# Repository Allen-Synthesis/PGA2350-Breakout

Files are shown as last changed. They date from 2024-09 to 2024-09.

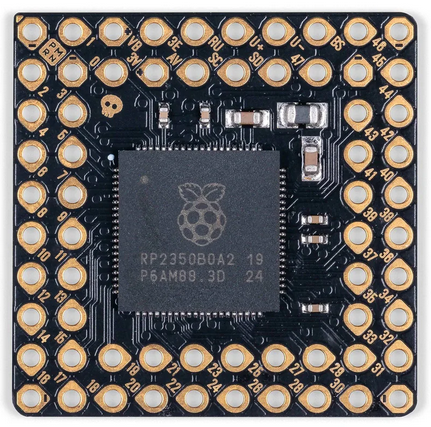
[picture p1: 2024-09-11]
images/PGA2350.png

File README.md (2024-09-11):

# PGA2350-breakout
### Pimoroni PGA2350 Breakout board for breadboard development of Eurorack modules



At the time I'm writing this, the only development board I can find for sale which utilises the B variant of the RP2350 *and* breaks out all of the extra ADCs it offers, is the [Pimoroni PGA2350](https://shop.pimoroni.com/products/pga2350?variant=42092629229651), however it is not a breadboard compatible.  
This board adapts the PGA2350 to allow it to be used for Eurorack development with a breadboard, breaking out all required connections including routing Eurorack power from a standard header to pin headers which can be connected to a breadboard's rails using jumper wire.  
The USB connections are arranged so that an [Adafruit USB Micro-B Breakout Board](https://www.adafruit.com/product/1833) (also sold by [Pimoroni](https://shop.pimoroni.com/products/adafruit-usb-micro-b-breakout-board?variant=821196557)) can be soldered directly to the board.

*NOTE: The first PCB order for these boards was tested on 10/09/2024 and appears to all work as expected. Not every GPIO has been tested, however the design is likely functional. Aesthetic improvements for version 1.1 (outlined below) have now been applied but no new boards have yet been ordered for testing. Order using the files in this repository with my blessing but at your own risk*

Pending changes based on version 1.0:
1. ~~Increment version to 1.1~~
1. ~~Alter pin header footprints to remove square pad for 1x2, 1x5, and 2x5~~
1. ~~Add JLC PCB order number text to the back~~
1. ~~Use consistent . or / in version date~~
1. ~~Remove J12 reference text~~
1. ~~Add ground stitching vias~~
1. ~~Use arrow to label PGA2350 and then use internal space to show orientation~~
1. Measure the USB breakout board and adjust position so that the edge is flush (USB already flush enough)
1. ~~Add lines between the labels and pins for rest of the headers as has been done for the GPIO headers~~
1. Add artwork to the back (and front?) to make use of the space (Text rearranged and logos swapped to copper layer, no more art added)

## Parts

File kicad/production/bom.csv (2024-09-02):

Designator | Footprint | Quantity | Value | LCSC Part #
J1, J11, J3, J9 | pin-socket-2.54mm-01x02 | 4 | Conn_01x02_Pin
J10, J5, J6, J7, J8 | pin-socket-2.54mm-02x05 | 5 | Conn_02x05_Counter_Clockwise
J12 | pin-header-2.54mm-01x03 | 1 | Conn_01x03_Pin
J2 | power-header-10-pin | 1 | Conn_02x05_Odd_Even
J4 | pin-header-2.54mm-01x05 | 1 | Conn_01x05_Pin
U1 | PGA2350 | 1 | ~

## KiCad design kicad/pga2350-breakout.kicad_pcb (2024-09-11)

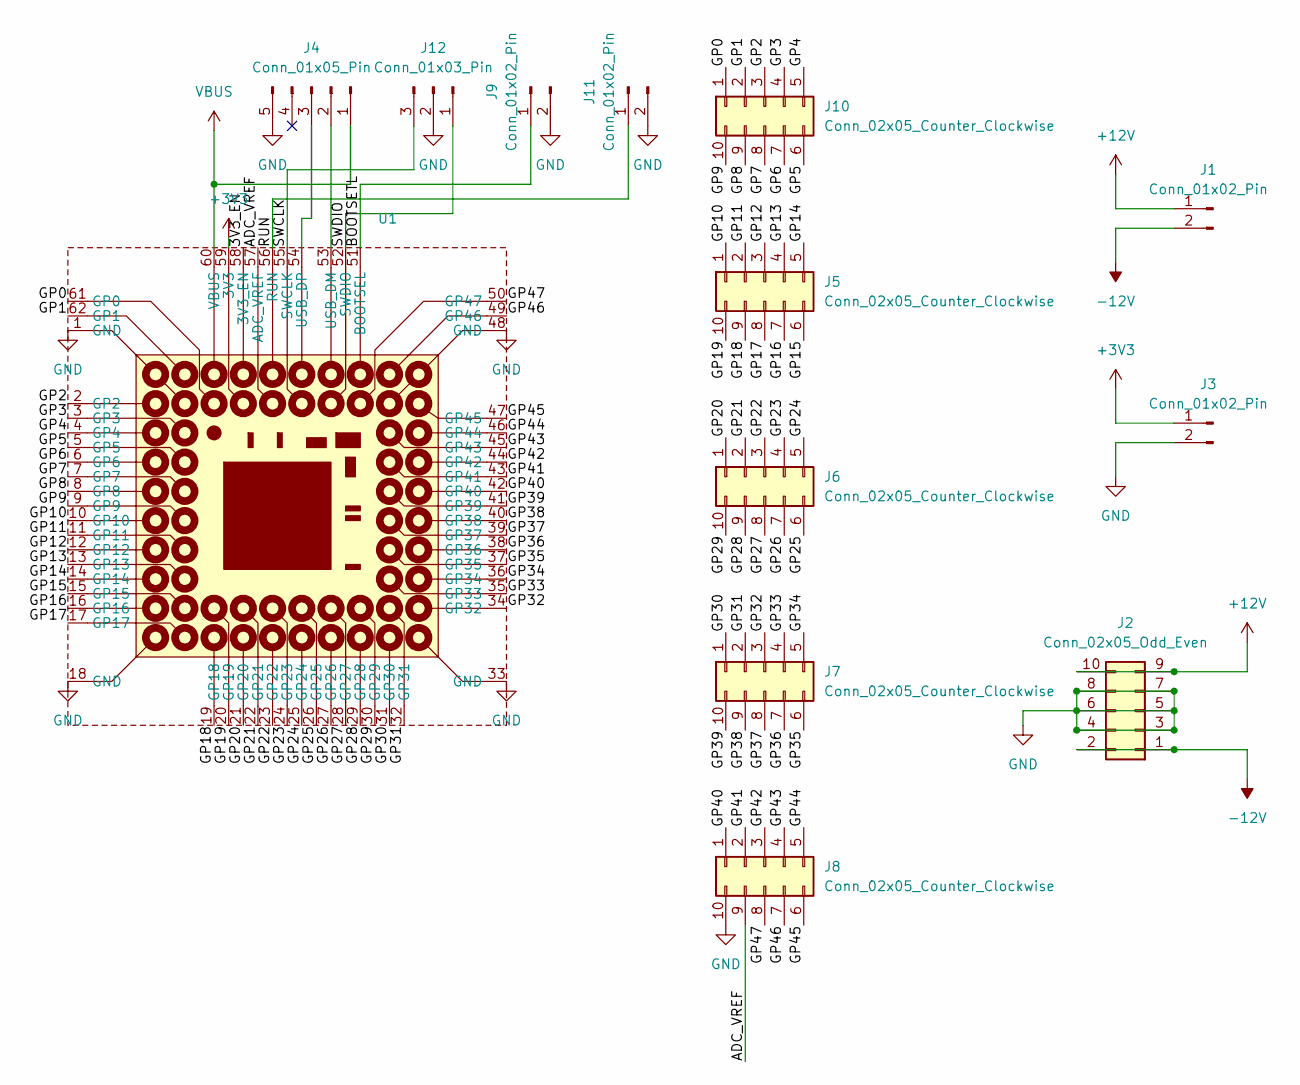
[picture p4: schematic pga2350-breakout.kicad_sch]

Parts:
J1, J3, J9, J11: Conn_01x02_Pin; pin-socket-2.54mm-01x02
J2: Conn_02x05_Odd_Even; power-header-10-pin
J4: Conn_01x05_Pin; pin-header-2.54mm-01x05
J5, J6, J7, J8, J10: Conn_02x05_Counter_Clockwise; pin-socket-2.54mm-02x05
J12: Conn_01x03_Pin; pin-header-2.54mm-01x03
U1: PGA2350

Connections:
+3V3: J3.1, U1.59 (3V3)
+12V: J1.1, J2.9, J2.10
-12V: J1.2, J2.1, J2.2
/3V3_EN: U1.58 (3V3_EN)
/ADC_VREF: J8.9, U1.57 (ADC_VREF)
/BOOTSETL: J9.1, U1.51 (BOOTSEL)
/GP0: J10.1, U1.61 (GP0)
/GP1: J10.2, U1.62 (GP1)
/GP2: J10.3, U1.2 (GP2)
/GP3: J10.4, U1.3 (GP3)
/GP4: J10.5, U1.4 (GP4)
/GP5: J10.6, U1.5 (GP5)
/GP6: J10.7, U1.6 (GP6)
/GP7: J10.8, U1.7 (GP7)
/GP8: J10.9, U1.8 (GP8)
/GP9: J10.10, U1.9 (GP9)
/GP10: J5.1, U1.10 (GP10)
/GP11: J5.2, U1.11 (GP11)
/GP12: J5.3, U1.12 (GP12)
/GP13: J5.4, U1.13 (GP13)
/GP14: J5.5, U1.14 (GP14)
/GP15: J5.6, U1.15 (GP15)
/GP16: J5.7, U1.16 (GP16)
/GP17: J5.8, U1.17 (GP17)
/GP18: J5.9, U1.19 (GP18)
/GP19: J5.10, U1.20 (GP19)
/GP20: J6.1, U1.21 (GP20)
/GP21: J6.2, U1.22 (GP21)
/GP22: J6.3, U1.23 (GP22)
/GP23: J6.4, U1.24 (GP23)
/GP24: J6.5, U1.25 (GP24)
/GP25: J6.6, U1.26 (GP25)
/GP26: J6.7, U1.27 (GP26)
/GP27: J6.8, U1.28 (GP27)
/GP28: J6.9, U1.29 (GP28)
/GP29: J6.10, U1.30 (GP29)
/GP30: J7.1, U1.31 (GP30)
/GP31: J7.2, U1.32 (GP31)
/GP32: J7.3, U1.34 (GP32)
/GP33: J7.4, U1.35 (GP33)
/GP34: J7.5, U1.36 (GP34)
/GP35: J7.6, U1.37 (GP35)
/GP36: J7.7, U1.38 (GP36)
/GP37: J7.8, U1.39 (GP37)
/GP38: J7.9, U1.40 (GP38)
/GP39: J7.10, U1.41 (GP39)
/GP40: J8.1, U1.42 (GP40)
/GP41: J8.2, U1.43 (GP41)
/GP42: J8.3, U1.44 (GP42)
/GP43: J8.4, U1.45 (GP43)
/GP44: J8.5, U1.46 (GP44)
/GP45: J8.6, U1.47 (GP45)
/GP46: J8.7, U1.49 (GP46)
/GP47: J8.8, U1.50 (GP47)
/RUN: J11.1, U1.56 (RUN)
/SWCLK: J12.3, U1.55 (SWCLK)
/SWDIO: J12.1, U1.52 (SWDIO)
GND: J2.3, J2.4, J2.5, J2.6, J2.7, J2.8, J3.2, J4.5, J8.10, J9.2, J11.2, J12.2, U1.1 (GND), U1.18 (GND), U1.33 (GND), U1.48 (GND)
unnamed: J4.2, U1.53 (USB_DM)
unnamed: J4.3, U1.54 (USB_DP)
VBUS: J4.1, U1.60 (VBUS)

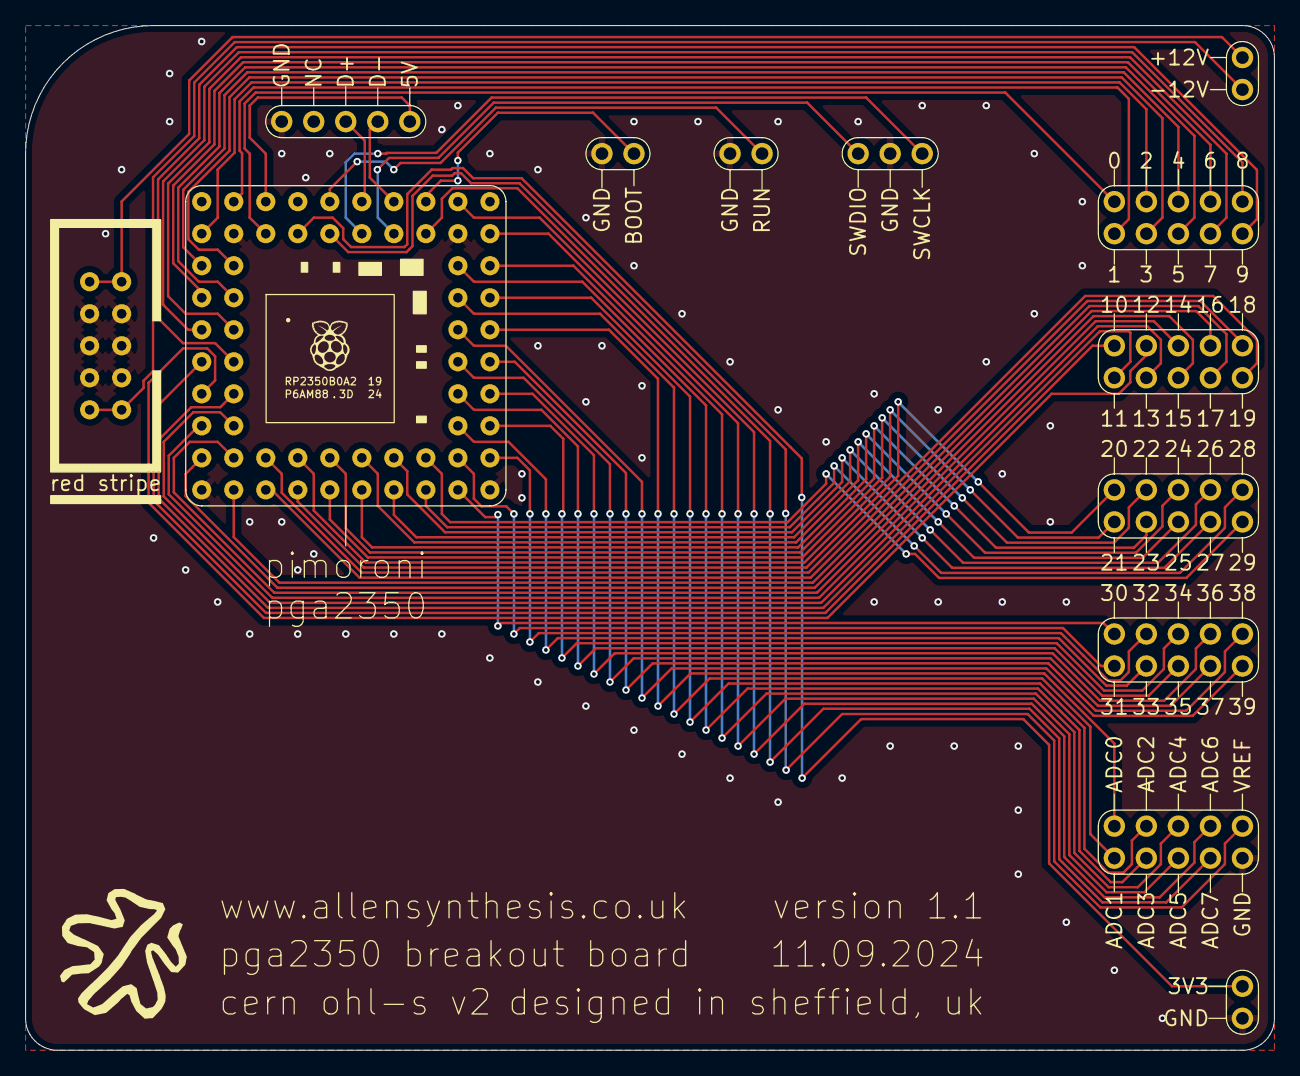
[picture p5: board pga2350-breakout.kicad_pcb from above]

Board: 2 copper layers, 99.1 x 81.3 mm, 13 parts (0 on the bottom side), 60 nets.

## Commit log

2024-09-02 add kicad files
    [pga2350-breakout.kicad_pcb, pga2350-breakout.kicad_sch]
2024-09-02 initial routing, DRC all clear
    [pga2350-breakout.kicad_pcb, pga2350-breakout.kicad_sch]
2024-09-02 save production version 1.0
    [bom.csv, designators.csv, pga2350-breakout.kicad_pcb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]
2024-09-02 add adc note
2024-09-02 add brackets for clarity
2024-09-11 version 1.1 updates
    [pga2350-breakout.kicad_pcb]
2024-09-11 move pga2350 label
    [pga2350-breakout.kicad_pcb]
2024-09-11 add ground stitching vias
    [pga2350-breakout.kicad_pcb]
2024-09-11 various updates
    [pga2350-breakout.kicad_pcb]

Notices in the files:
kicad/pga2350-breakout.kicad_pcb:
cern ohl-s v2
